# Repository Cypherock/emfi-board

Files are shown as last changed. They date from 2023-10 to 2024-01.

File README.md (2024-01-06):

# Cypherock EMFI Board

The Cypherock EMFI device is a low-cost Electromagnetic Fault Injection (EMFI) device, developed by Cypherock for studying and researching physical security threats that appear at a circuit level in modern chips.  

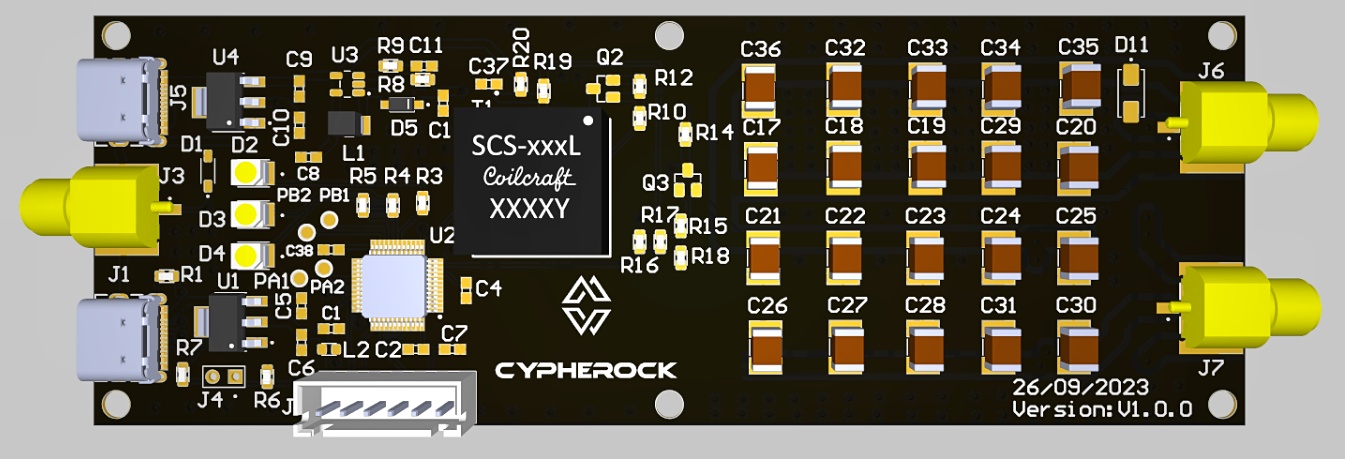
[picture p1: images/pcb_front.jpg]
pcb_front
      

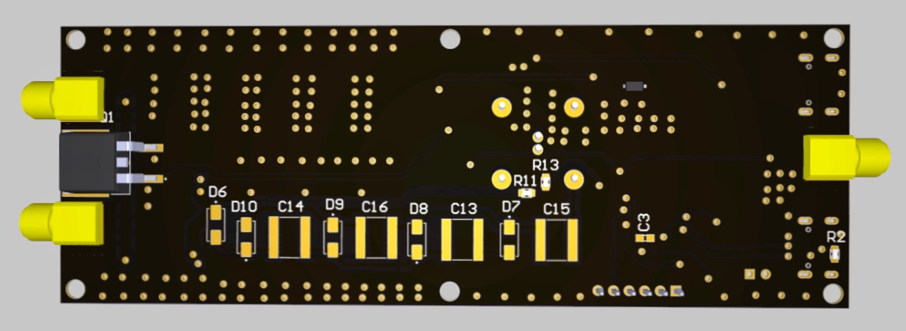
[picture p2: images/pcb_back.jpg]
pcb_back


## Background

Electromagnetic fault injection (EMFI) is used to disrupt the behavior of a chip and for weakening its security, typically targetting simple microcontrollers. It involves injecting electromagnetic shock at specific points on a target device's hardware to induce faults or errors. EMFI is one of the most common and popular physical attacks deployed or performed on various embedded systems, known for its capability to easily bypass and break through most of the security measures employed in modern chips. The following are two different attacks that can be performed using EMFI.

*Control Flow Manipulation Attacks* : 
Control flow manipulation in applications involves altering the execution order of instructions, often for malicious purposes. In embedded devices and microcontrollers, attackers can manipulate control flow without requiring vulnerabilities in the application code. Hardware attacks like voltage glitching, electromagnetic fault injection (EMFI), and laser fault injection (LFI) are employed to disrupt control flow and modify application code. These fault attacks can lead to unexpected behavior, including instruction skips, data corruption in memory, instruction modification, and tampering with the program counter. Such behavior can then be exploited by attackers to gain privileges, bypass security measures, extract information, inject malware, and more.

*Read Out Protection Bypass Attacks* : 
Read out protection (RDP) is a mechanism that restricts external access to the internals (flash memory and SRAM) of a microcontroller. Typically, this access is facilitated through a debug interface. However, depending on the application a microcontroller is used for, partial access might be sufficient for plotting attacks, for example only to the internal SRAM or some CPU registers. To compromise the RDP mechanism, physical attacks aims to interfere with the behavior of the underlying hardware implementations of a read-out protection. Again methods like voltage glitching and EMFI are perfect  for inducing faults in the MCUs code and operation. EMFI is a non-invasive attack method that does not require physical modifications to the microcontroller's hardware such as chip decapsulation etc. In practice, the read-out protection of some microcontrollers can be temporarily disabled and bypassed by applying a voltage glitch or injecting a pulse via EMFI during the power-up phase of the microcontrollers. 

## Working

The device is powered by USB. A programmable PWM signal is given as input from an STM32L4 MCU, this is used to control the output voltage (by changing the PWM parameters) generated by the device. When this signal is high the step up transformer will raise the voltage at its primary, converting the low voltage to high voltage at the secondary terminal. The step up transformer has primary to secondary winding ratio of 1:200. This voltage in the secondary is then again multiplied by a factor of “4” by the voltage multiplier and a very high voltage is generated. The charge is stored in the capacitor bank. All the capacitors used in this setup have a breakdown voltage of 1kV. The switching circuit is used to transfer this charge on to the EM probe. An external trigger or a controllable pulse is given as an input signal to the IGBT for a short period of time for switching. The external trigger can be given directly to the switching circuit to inject the fault, or through the MCU in which the MCU can modify or add delays to the signal programmatically. The MCU on its own can also be used to generate the pulse. When the IGBT is in ON state, the high voltage is transferred to the load which is the EM probe. Due to the high current that circulates in the coil of the probe, a magnetic field would be generated and the probe uses this electromagnetic field to transfer an electromagnetic shock to the DUT, injecting faults.

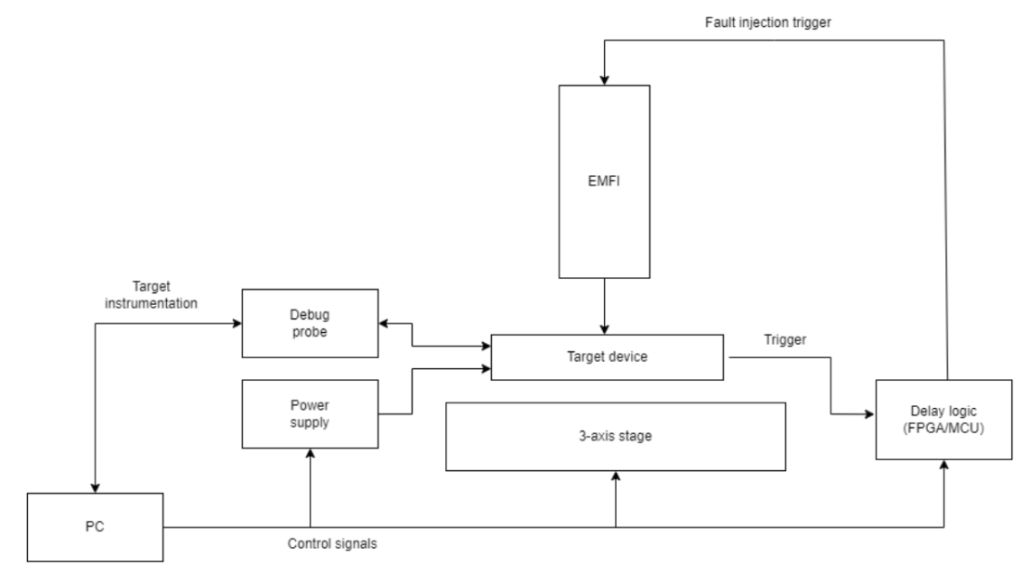
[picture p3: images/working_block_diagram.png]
working_block_diagram


The target microcontroller could be mounted on a 3-axis position stage. With this, the injection coil can be positioned precisely on the device and an automated grid scan can be performed. To ensure that the target device is always in a defined state, a programmable power supply source to power cycle the microcontroller should be used. Power-cycling could be applied before each measurement or for recovery, if the faulted microcontroller malfunctions. With the delay generator capability within the EMFI board, it is ensured that the fault is injected at the right point in time. A host PC could be used to control the entire setup and instrument the target microcontroller via a debug probe.

## Features

* Supports external power supply.  
* Supports external trigger or signal as input to generate pulse. 
* Supports modifying the signal programmatically.
* Programmable High Voltage Generation.
* Protection case to eliminate exposure to high voltage circuitry and for safe operation.
* Three on board LEDs for which can be used as indicators such as warning light etc.
* Low Input Power Requirement.
* Controlled Shock Injection.
* Two SMA Connectors to facilitate changing the polarity of the injected EM pulse.

## Electromagnetic (EM) Probe

The EM probe is required to inject shock into the target DUT. It can be constructed easily using a [power inductor](https://www.mouser.in/ProductDetail/710-744710610) and an [SMA connector](https://www.mouser.in/ProductDetail/712-CONSMA013.062-G). The power inductor would have a ferrite core wrapped around with coil. It converts the electrical energy into magnetic energy. The power inductor can be connected to an SMA connector to complete this setup. 

## Device Under Test (DUTs)   

The below list shows the microcontrollers that are commonly used in hardware crypto wallets. These microcontrollers are susceptible to EMFI based attacks. We have designed the DUT boards for EMFI analysis on these microcontrollers. These boards are included inside the hardware folder.

* STM32F205RET6
* STM32F427VIT6TR
* STM32L496RGT6
* STM32H753VIT6
* ESP32-D0WD-V3
* ATSAMD51J20A-AU
* ATMEGA328P-AU

## Usage

### EMFI firmware 
- STM32CubeIDE is required for building and debugging the project.
- After installation of the IDE, the project can be accessed by either using the .project/.cproject files.
- Use the launch configurations for debugging and programming the EMFI board.

### Use the EMFI tool for generating shoots
- Install python dependencies from requirements.txt
- Connect EMFI board's power and USB comm ports
- Run the python in Scripts/Cypherock/test.py
- Enter the COM port detected on the system
- After connection is created, EMFI voltage would start rising
- On pressing enter on the terminal, the device would start a EMFI shoot
- On pressing enter again, the device would turn off the PWM and voltage would gradually decrease

## License

Cypherock EMFI Board is released under [GNU General Public License](https://www.gnu.org/licenses/gpl-3.0.en.html) Version 3.

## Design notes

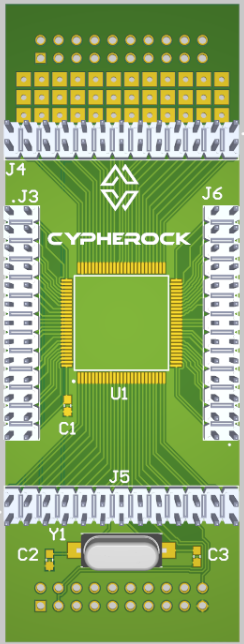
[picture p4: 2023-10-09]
images/DUT_STM32H753VIT6.png

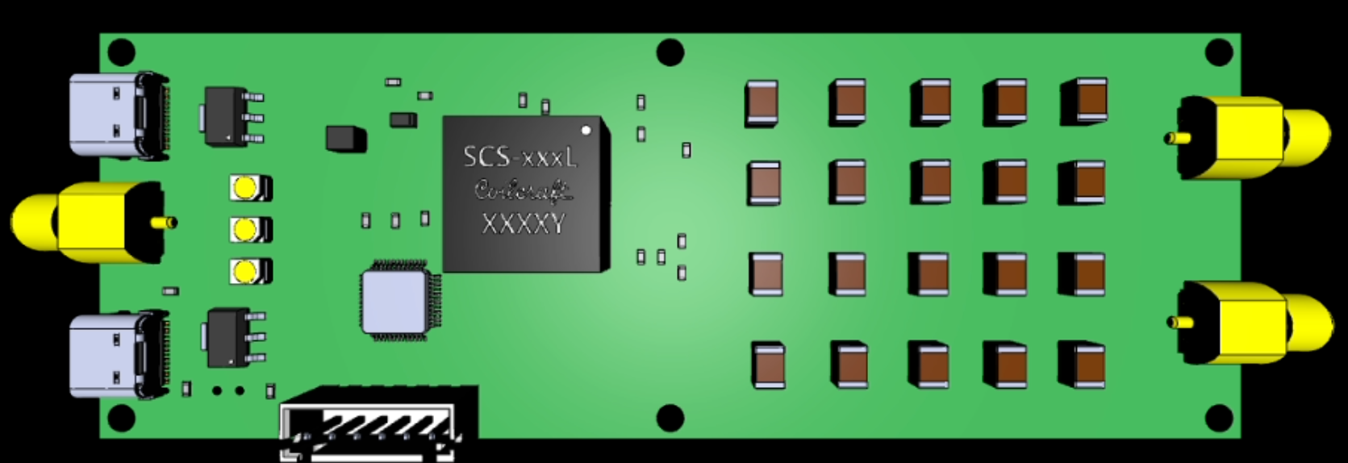
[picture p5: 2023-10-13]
images/pcb_3d_front.png

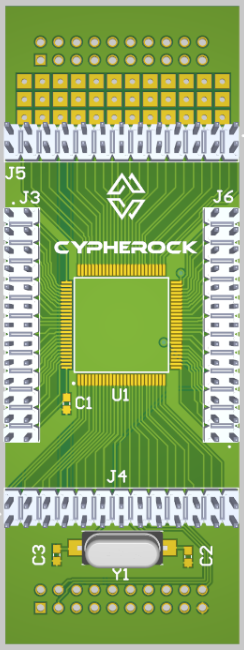
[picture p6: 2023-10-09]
images/DUT_STM32F427VIT6TR.png

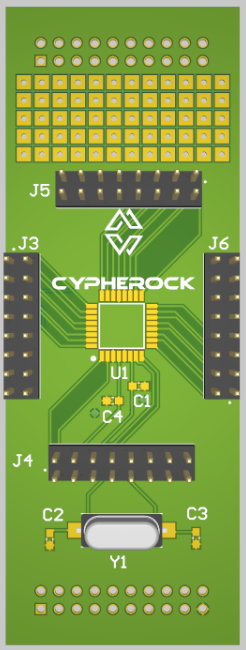
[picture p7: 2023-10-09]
images/DUT_ATMEGA328P-AU.png

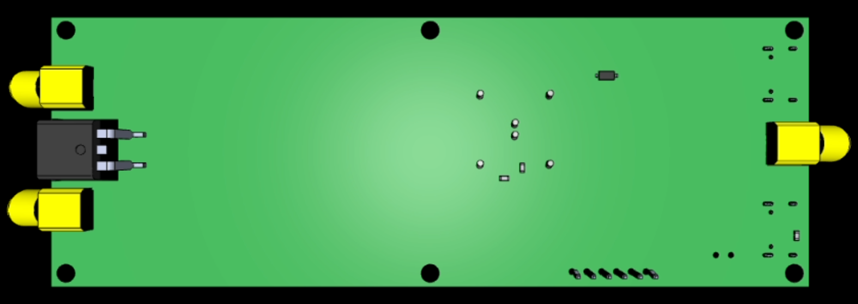
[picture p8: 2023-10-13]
images/pcb_3d_back.png

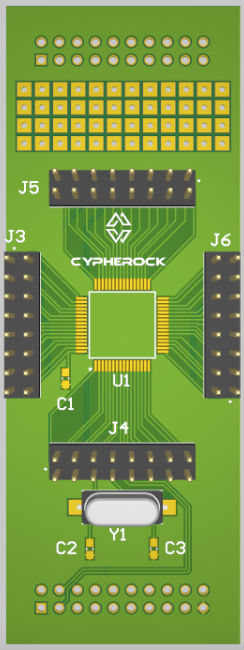
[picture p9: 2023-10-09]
images/DUT_STM32L496RGT6.png

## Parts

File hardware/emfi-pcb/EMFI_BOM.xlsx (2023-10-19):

Designator | Part Number | Description / Value | Package Description | Qty.
C1, C12 | GRM188Z71C475KE21D | 4.7uF/16V | 603 | 2
C2, C3, C4, C38 | CL10B105KO8NFNC | 1uF/16V | 603 | 4
C5, C6, C7, C8, C9, C10, C37 | GRT188R61C106KE13J | 10uF/16V | 0603, CAP CER 10UF 16V X5R 0603 | 7
C11 | VJ0603A4R7BXJPW1BC | 4.7pF/16V | 603 | 1
C13, C14, C15, C16 | C2225X154KDRACTU | 0.15uF/1000V | 2225 | 4
C17, C18, C19, C20, C21, C22, C23, C24, C25, C26, C27, C28, C29, C30, C31, C32, C33, C34, C35, C36 | C1812C104KDRAC7210 | 0.1uF/1000V | 1812 | 20
D1 | BZT52C3V3 | Zener Diode - Zener, SOD-123F, 3.3V, 0.5W, 5% | SOD-123F | 1
D2, D3, D4 | AA3528LSECKT/J4 | Standard LEDs - SMD 3.5mmX2.8mm SMD LED LAMP ORANGE | PLCC2 | 3
D5 | MBR0530T1G | Schottky Diodes & Rectifiers 0.5A 30V | SOD-123 | 1
D6, D7, D8, D9, D10, D11 | FR1M | Rectifiers Diode, Fast, SMA, 1000V, 1A, 150C | Diode Standard 1000 V 1A Surface Mount DO-214AC (SMA) | 6
J1, J5 | USB4105-GF-A-060 | USB Type-C | USB-C (USB TYPE-C) USB 2.0 Receptacle Connector 24 (16+8 Dummy) Position Surface Mount, Right Angle; Through Hole | 2
J2 | MP001799 | Pin Header - 2.5mm, 1 row 6 contact | Connector Header Through Hole 6 position 0.098 (2.50mm) | 1
J3, J6, J7 | SMA-J-P-H-ST-EM3 | SMA - RF Connectors / Coaxial Connectors 6 GHz, 50 Ohm SMA Jack or Plug, Cable Connector | RF Connectors / Coaxial Connectors | 3
J4 | 87224-2 | Connector Unshrouded Header HDR 2 Position 2.54mm Solder Straight Thru-Hole | Connector Unshrouded Header HDR 2 Position 2.54mm Solder Straight Thru-Hole | 1
L1 | NLCV32T-6R8M-EF | RF Inductor - 6.8uH | 1210 | 1
L2 | MPZ1608S102ATD25 | Ferrite Beads 0603 1000ohms 800mA Power Line AEC-Q200 | 603 | 1
PA1, PA2, PB1, PB2 | 5019 |  | SMT Test Point- Mininature-1000 pc Reels | 4
Q1 | IXGA30N120B3 | IGBT Transistor - GenX3 1200V IGBT | TO-263-3 | 1
Q2, Q3 | IRLML6344TRPBF | MOSFET - N channel - 40Vds 20Vgs 20A 5.0A 93pF 1.2W | SOT-23-3 | 2
R1, R2 | CRCW06034K75FKEA | 4.75k/0.1W | RES 0.27 OHM 1% 1/10W 0603 | 2
R3, R4, R5 | RT0603FRE072KL | 2k/0.1W | RES 0.27 OHM 1% 1/10W 0603 | 3
R6, R12, R13, R14, R15, R18 | RC0603FR-0710KL | 10k/0.1W | RES 0.27 OHM 1% 1/10W 0603 | 6
R7, R19 | AC0603FR-070RL | 0E/0.1W | RES 0.27 OHM 1% 1/10W 0603 | 2
R8 | CRCW06031M80FKEAC | 1.8M/0.1W | RES 0.27 OHM 1% 1/10W 0603 | 1
R9 | RC0603FR-07205KL | 205k/0.1W | RES 0.27 OHM 1% 1/10W 0603 | 1
R10, R17 | CRCW0603100RFKEAC | 100E/0.1W | RES 0.27 OHM 1% 1/10W 0603 | 2
R11 | CRCW060310M0FKEAC | 10M/0.1W | RES 0.27 OHM 1% 1/10W 0603 | 1
R16, R20 | AC0603FR-070RL | 0E/0.1W DNP | RES 0.27 OHM 1% 1/10W 0603 | 2
T1 | SCS-200LD | Transformer |  | 1
U1, U4 | TLV1117LV33 | Voltage Regulator - LDO Voltage Regulators LDO BJT | 1-A, low-dropout voltage regulator | 2
U2 | STM32L412C8T6 | MCU | STMICROELECTRONICS - STM32L412C8T6 - MCU, 32BIT, 80MHZ | 1
U3 | TPS61040QDBVRQ1 | Switching Voltage Regulators Auto Cat Low Pwr DC/DC Boost Cnvrtr |  | 1

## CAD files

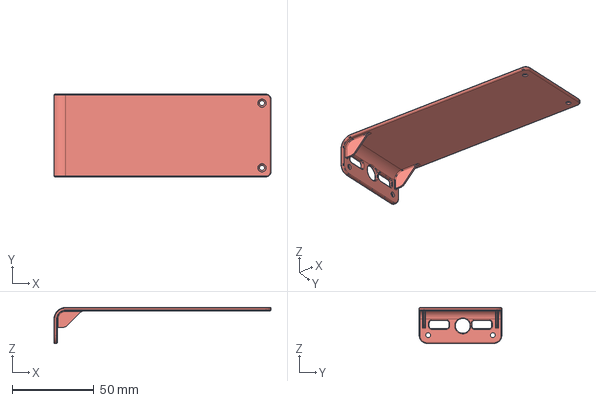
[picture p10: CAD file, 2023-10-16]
hardware/emfi-enclosure/enclosure_top.step
132.6 x 50.5 x 22.0 mm

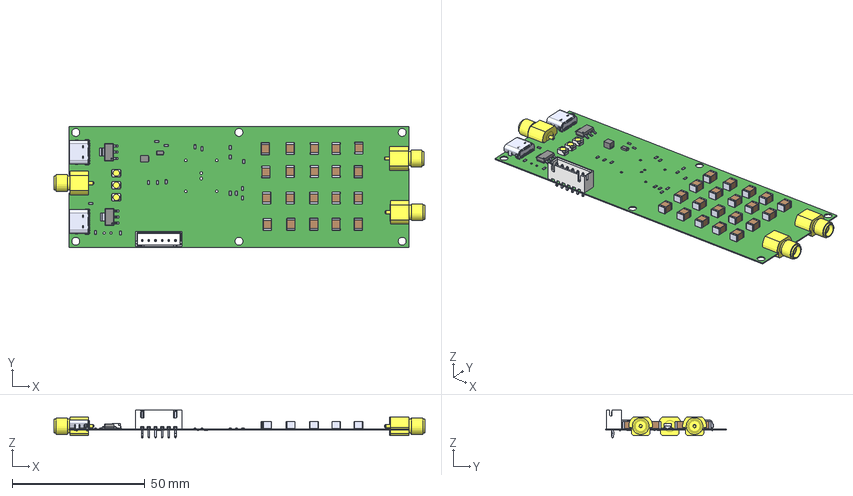
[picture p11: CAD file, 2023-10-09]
hardware/emfi-pcb/EMFI_3D.step
139.8 x 45.6 x 10.4 mm
USB4105 x 2
SMA-J-P-H-ST-EM3 x 3

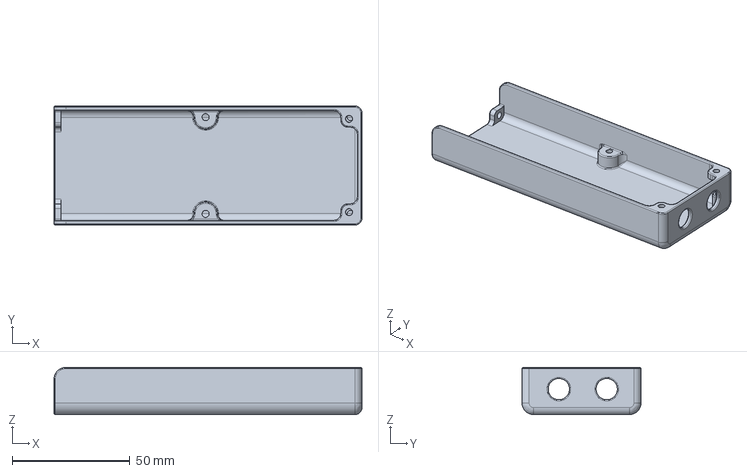
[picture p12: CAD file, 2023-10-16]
hardware/emfi-enclosure/enclosure_bottom.step
130.6 x 50.5 x 20.0 mm

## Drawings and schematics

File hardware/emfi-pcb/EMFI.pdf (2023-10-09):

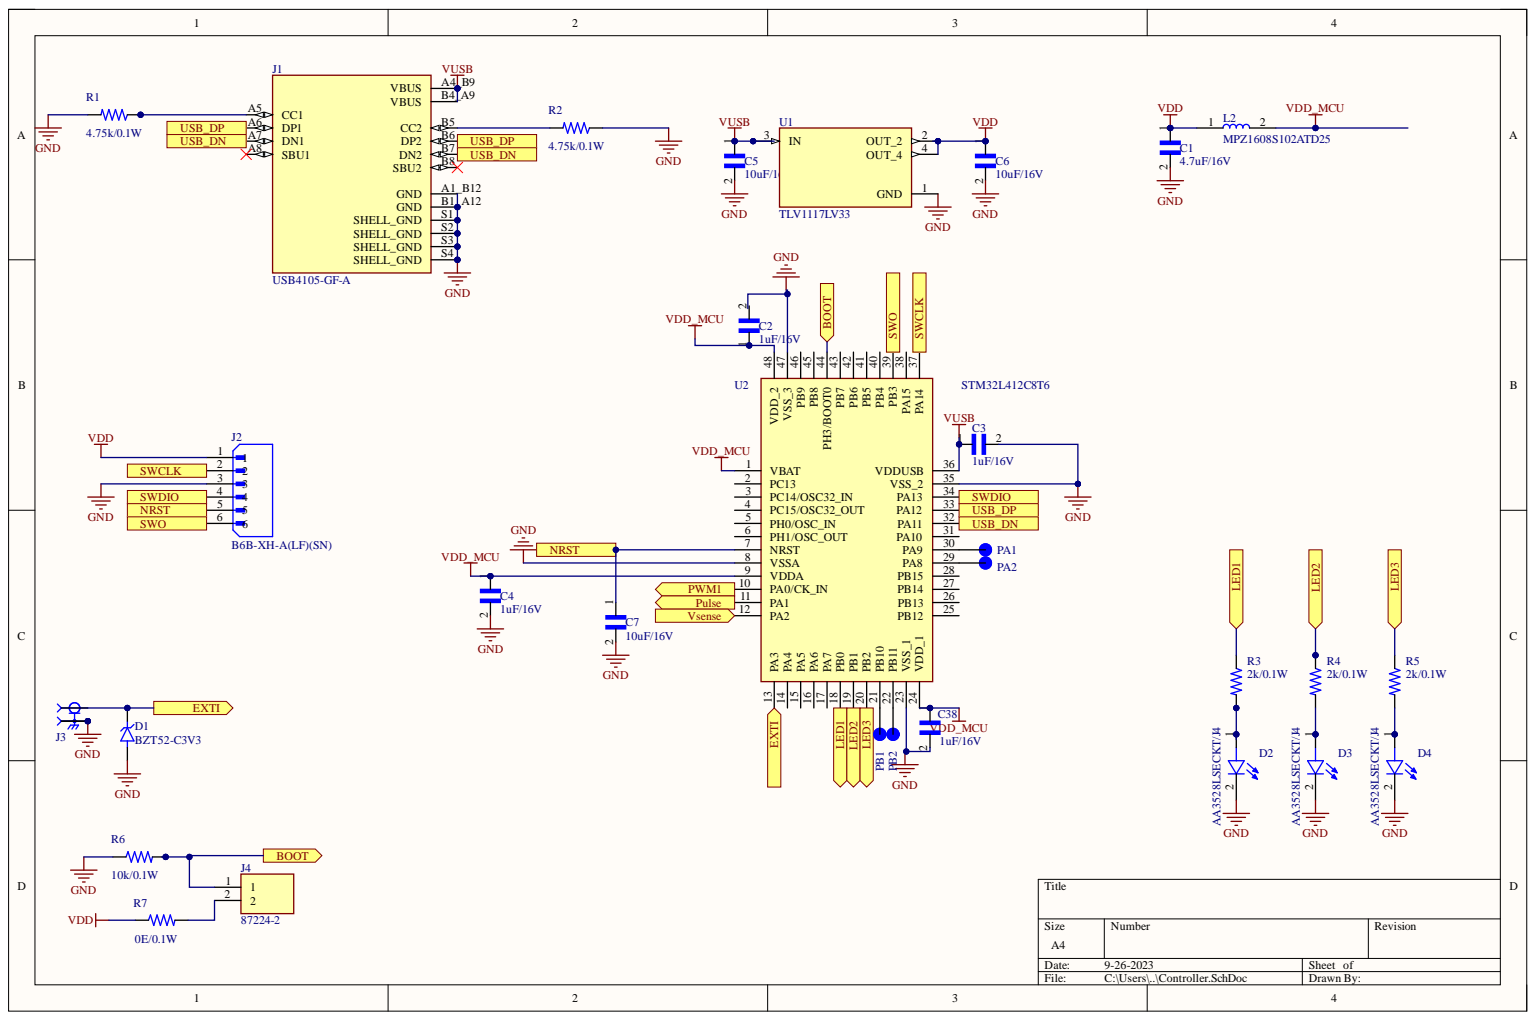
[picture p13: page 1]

VSSA 8

PWM1 | PA0/CK_IN 10

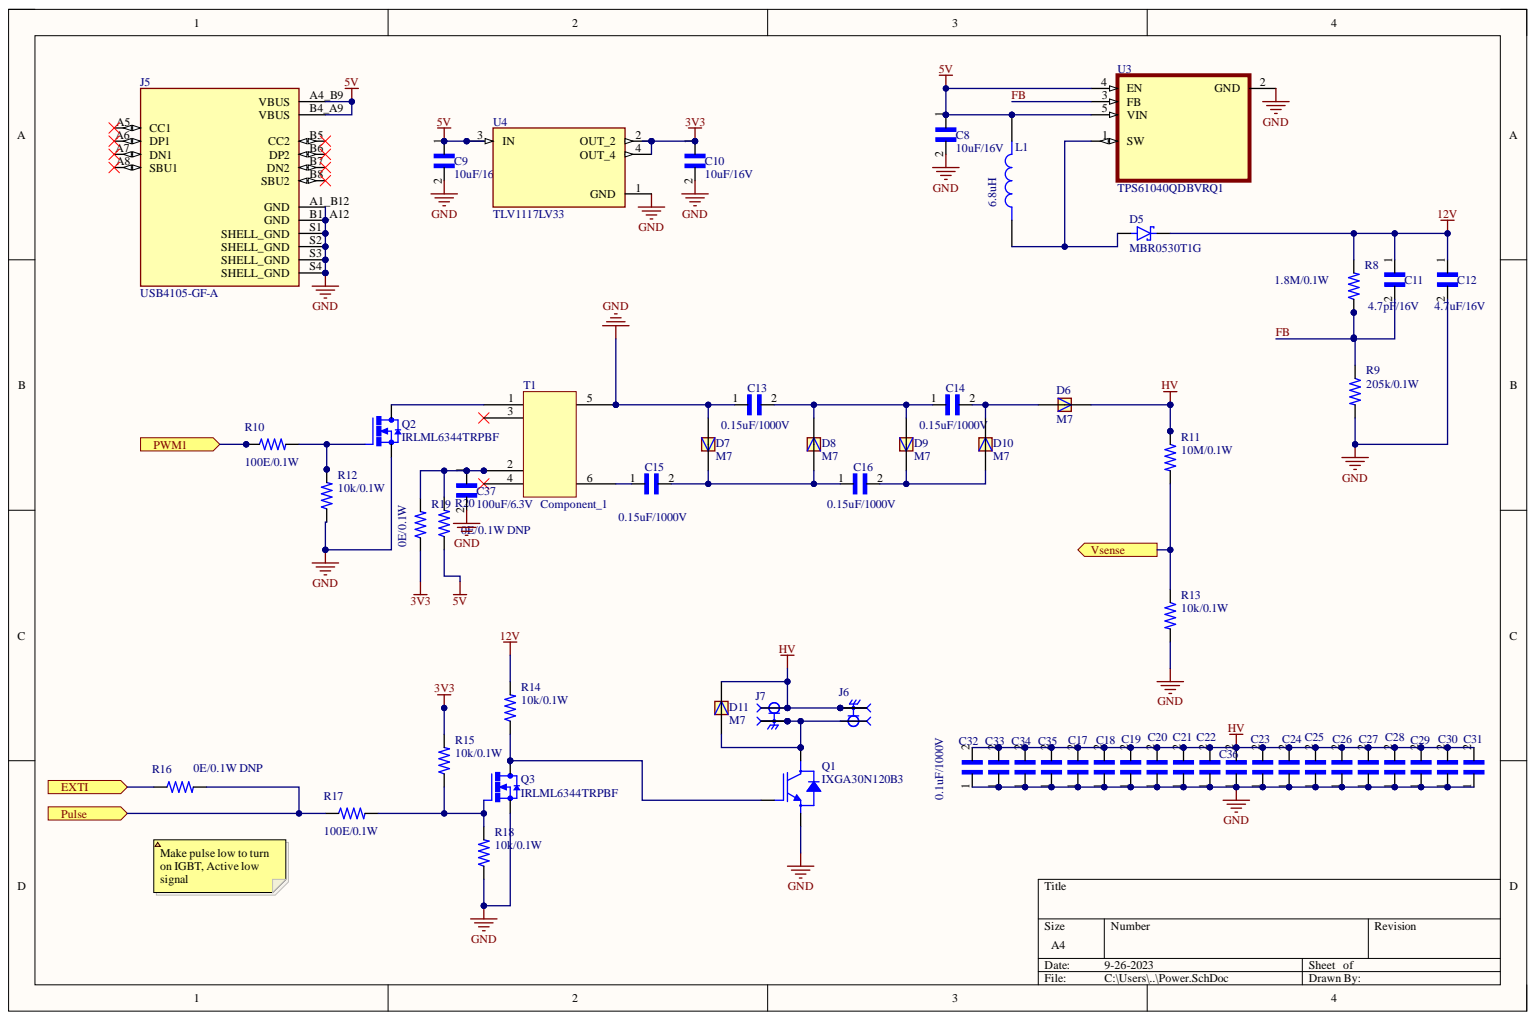
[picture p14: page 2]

Make pulse low to turn
on IGBT, Active low
signal

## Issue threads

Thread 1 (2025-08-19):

Fatal error in Q1 driver !!!

trojkowy, 2025-08-19:
This design has some bugs. After fully assembling the device and connecting it to the supply voltage, Q1 self-excites and blows up. 1. This transistor should be controlled by a gate driver not by Q3! . 2. You have two logical states set in Q3 via R15 to VCC and via R18 to GND. Even if you remove one logical state by desoldering the resistor, each subsequent Q1 still lights up and blows up. During my third attempt to replace the burned-out Q1 with a new one from the MOUSER store, this time I fried many other components, including the STM32 processor. Thank you f

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

or this wonderful project!

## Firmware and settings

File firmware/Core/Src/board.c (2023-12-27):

/*
 * board.c
 *
 *  Created on: Nov 5, 2023
 *      Author: akuan
 */
#include "board.h"

#include "pid.h"
ADC_HandleTypeDef hadc1;
DMA_HandleTypeDef hdma_adc1;

TIM_HandleTypeDef htim2;
TIM_HandleTypeDef htim6;

PID_TypeDef TPID;
system_info_t sysInfo;
uint8_t performShoot = 1;

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
/* USER CODE BEGIN 4 */
uint16_t BSP_DMA_Count(void)
{
	uint16_t count =  __HAL_DMA_GET_COUNTER(&hdma_adc1);
	return count;
}

void BSP_TIM_PWM_CH1_Start(void)
{
	HAL_TIM_PWM_Start(&htim2, TIM_CHANNEL_1);
}

void BSP_TIM_PWM_CH2_Start(void)
{
	HAL_TIM_PWM_Start(&htim2, TIM_CHANNEL_2);
}

void BSP_Start_ADC_IT(void)
{

	HAL_ADC_Start_IT(&hadc1);
}

HAL_StatusTypeDef BSP_ReadVoltage(uint16_t *pData, uint16_t Size)
{
	HAL_StatusTypeDef status = HAL_OK;
	status = HAL_ADC_Start_DMA(&hadc1, (uint32_t*)pData, Size);
	if (status != HAL_OK)
		return HAL_ERROR;
	return HAL_OK;
}

void HAL_TickCallBack(void)
{


}
uint8_t isPWM_Generation_Start = 0;
uint8_t isPWM_Stoped = 0;
uint32_t adc_set_point_value = 400;


void update_dutyCycle()
{
	int diffValue =  adc_set_point_value - sysInfo.adcDataReadBuffer;

	uint32_t percentValue = ((float)diffValue / adc_set_point_value) *100;
	if (percentValue < 0)
	{
		HAL_TIM_PWM_Stop(&htim2, TIM_CHANNEL_1);
	}
	else if ((percentValue < 40) && percentValue)
	{
		TIM2->CCR1  = (39) *percentValue;
	}
	else if (percentValue == 0)
	{
		TIM2->CCR1 = (39);
	}
	else
	{
		TIM2->CCR1 = 1599;
	}

}
void HAL_ADC_ConvCpltCallback(ADC_HandleTypeDef* hadc)
{
	// Read & Update The ADC Result
	sysInfo.adcDataReadBuffer = HAL_ADC_GetValue(&hadc1);
	sysInfo.adcDataReadBuffer += (sysInfo.PIDOut / 100);
	//PID_Compute(&TPID);
	if (isPWM_Generation_Start)
	{
		if (sysInfo.adcDataReadBuffer > adc_set_point_value)
		{
			if (isPWM_Stoped == 0)
			{
				HAL_TIM_PWM_Stop(&htim2, TIM_CHANNEL_1);
				HAL_GPIO_WritePin(GPIOB,LED3_PIN_Pin, GPIO_PIN_SET);
				isPWM_Stoped = 1;
			}
		}
		else
		{
			if (isPWM_Stoped)
			{
				//sysInfo.CH1_ARR = ((3*pwmValue->pwmWidth) - 1);
				//sysInfo.CH1_DC = (((sysInfo.CH1_ARR + 1) /100) *(pwmValue->pwmPeriod));
				TIM2->CCR1 = 399;
				TIM2->ARR = 3999;
				HAL_TIM_PWM_Start(&htim2, TIM_CHANNEL_1);
				isPWM_Stoped = 0;
			}

			HAL_GPIO_WritePin(GPIOB,LED3_PIN_Pin, GPIO_PIN_RESET);

			//update_dutyCycle();


		}
	}
}


void BSP_Config_PID(void)
{

	PID(&TPID, &sysInfo.Volt, &sysInfo.PIDOut, &sysInfo.VoltSetpoint, 2, 5, 1, _PID_P_ON_E, _PID_CD_DIRECT);

	PID_SetMode(&TPID, _PID_MODE_AUTOMATIC);
	PID_SetSampleTime(&TPID, 500);
	PID_SetOutputLimits(&TPID, -100, 100);
}

#include "usbd_cdc_if.h"
uint8_t SendBuffer[128] = { 0 };
uint8_t commandResponce = 0;
typedef struct
{
	uint16_t pwmWidth;
	uint16_t pwmPeriod;

}pwm_setting_t;
pwm_setting_t pwmSetting = { 800, 1};
uint8_t dataRead[128] = { 0 };
void parse_cmd(uint8_t cmd, uint8_t * data, uint8_t size)
{
	switch(cmd)
	{
		case ACTIVATE_VOLT_GENERATER:
		{
			commandResponce = cmd;
			CDC_Transmit_FS((uint8_t *)&commandResponce, sizeof(uint8_t));
			uint8_t * value = (uint8_t *)data;
			isPWM_Generation_Start = *value;
			isPWM_Stoped = 1;
			//isPWM_Generation_Start = 1;
			break;
		}

		case GET_RAW_VALUE:
		{
			uint16_t readAdc = sysInfo.adcDataReadBuffer;
			CDC_Transmit_FS((uint8_t *)&readAdc, sizeof(uint16_t));
			break;
		}

		case SET_PWM_VALUE:
		{

			CDC_Transmit_FS((uint8_t *)&cmd, 1);
			pwm_setting_t * pwmValue = (pwm_setting_t *)data;

			sysInfo.CH1_ARR = ((3*pwmValue->pwmWidth) - 1);
			sysInfo.CH1_DC = (((sysInfo.CH1_ARR + 1) /100) *(pwmValue->pwmPeriod));
			//BSP_TIM_PWM_CH1_Start();
			break;
		}


		case PERFORM_SOFTWARE_SHOOT:
			CDC_Transmit_FS((uint8_t *)&cmd, 1);
			TIM6_Start();
			nopCount++;
			performShoot = 1;
			break;
		case GET_SYSTEM_TIME:
		{
			uint64_t currentTime = HAL_GetTick();
			memcpy(SendBuffer,(uint8_t *)&currentTime,sizeof(uint64_t));
			CDC_Transmit_FS((uint8_t *)&SendBuffer, sizeof(uint64_t));
		}
			break;
		case GET_ADC_CONTROL_SETPOINT:
			CDC_Transmit_FS((uint8_t *)&sysInfo.pidLimit.setpoint, sizeof(uint32_t));
			break;
		case SET_ADC_CONTROL_SETPOINT:
			break;
		case GET_PWM_VALUE:

			CDC_Transmit_FS((uint8_t *)&pwmSetting.pwmWidth, sizeof(uint32_t));
			pwmSetting.pwmPeriod = 5;
			CDC_Transmit_FS((uint8_t *)&pwmSetting.pwmPeriod, sizeof(uint32_t));
			break;
		case READ_PID_VALUE:
			memcpy(SendBuffer,(uint8_t *)&sysInfo.pidConfig,sizeof(pid_config_t));
			CDC_Transmit_FS((uint8_t *)&SendBuffer, sizeof(pid_config_t));
			break;
		case SET_PID_VALUE:
			break;
		case SET_PID_LIMIT_VALUE:
			break;
		case READ_PID_LIMIT_VALUE:
			memcpy(SendBuffer,(uint8_t *)&sysInfo.pidLimit,sizeof(pid_limit_t));
			CDC_Transmit_FS((uint8_t *)&SendBuffer, sizeof(pid_limit_t));
			break;
		case SET_ADC_SET_POINT:
		{
			uint16_t * value = (uint16_t *)data;
			adc_set_point_value = *value;
			break;
		}
	}
}
/* USER CODE END 4 */

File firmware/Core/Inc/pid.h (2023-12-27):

 /*
------------------------------------------------------------------------------
~ File   : pid.h
~ Author : Majid Derhambakhsh
~ Version: V1.0.0
~ Created: 02/11/2021 03:43:00 AM
~ Brief  :
~ Support:
		   E-Mail : Majid.do16@gmail.com (subject : Embedded Library Support)

		   Github : https://github.com/Majid-Derhambakhsh
------------------------------------------------------------------------------
~ Description:

~ Attention  :

~ Changes    :
------------------------------------------------------------------------------
*/

#ifndef __PID_H_
#define __PID_H_

/* ~~~~~~~~~~~~~~~~~~~~~~~~~~~~~~~~~~~~~~~~~~~~~~~~~~~~~~~~~~ Include ~~~~~~~~~~~~~~~~~~~~~~~~~~~~~~~~~~~~~~~~~~~~~~~~~~~~~~~~~~ */
#include <stdint.h>
#include <string.h>

/* ------------------------------------------------------------------ */

#ifdef __CODEVISIONAVR__  /* Check compiler */

#pragma warn_unref_func- /* Disable 'unused function' warning */

/* ------------------------------------------------------------------ */

#elif defined(__GNUC__) && !defined(USE_HAL_DRIVER)  /* Check compiler */

#pragma GCC diagnostic ignored "-Wunused-function" /* Disable 'unused function' warning */

/* ------------------------------------------------------------------ */

#elif defined(USE_HAL_DRIVER)  /* Check driver */

	#include "main.h"

	/* --------------- Check Mainstream series --------------- */

	#ifdef STM32F0
		#include "stm32f0xx_hal.h"       /* Import HAL library */
	#elif defined(STM32F1)
		#include "stm32f1xx_hal.h"       /* Import HAL library */
	#elif defined(STM32F2)
		#include "stm32f2xx_hal.h"       /* Import HAL library */
	#elif defined(STM32F3)
		#include "stm32f3xx_hal.h"       /* Import HAL library */
	#elif defined(STM32F4)
		#include "stm32f4xx_hal.h"       /* Import HAL library */
	#elif defined(STM32F7)
		#include "stm32f7xx_hal.h"       /* Import HAL library */
	#elif defined(STM32G0)
		#include "stm32g0xx_hal.h"       /* Import HAL library */
	#elif defined(STM32G4)
		#include "stm32g4xx_hal.h"       /* Import HAL library */

	/* ------------ Check High Performance series ------------ */

	#elif defined(STM32H7)
		#include "stm32h7xx_hal.h"       /* Import HAL library */

	/* ------------ Check Ultra low power series ------------- */

	#elif defined(STM32L0)
		#include "stm32l0xx_hal.h"       /* Import HAL library */
	#elif defined(STM32L1)
		#include "stm32l1xx_hal.h"       /* Import HAL library */
	#elif defined(STM32L5)
		#include "stm32l5xx_hal.h"       /* Import HAL library */
	#elif defined(STM32L4)
		#include "stm32l4xx_hal.h"       /* Import HAL library */
	#elif defined(STM32H7)
		#include "stm32h7xx_hal.h"       /* Import HAL library */
	#else
	#endif /* STM32F1 */

	/* ------------------------------------------------------- */

	#if defined ( __ICCARM__ ) /* ICCARM Compiler */

	#pragma diag_suppress=Pe177   /* Disable 'unused function' warning */

	#elif defined   (  __GNUC__  ) /* GNU Compiler */

	#pragma diag_suppress 177     /* Disable 'unused function' warning */

	#endif /* __ICCARM__ */

/* ------------------------------------------------------------------ */

#else                     /* Compiler not found */

#error Chip or Library not supported  /* Send error */

#endif /* __CODEVISIONAVR__ */

/* ------------------------------------------------------------------ */

/* ~~~~~~~~~~~~~~~~~~~~~~~~~~~~~~~~~~~~~~~~~~~~~~~~~~~~~~~~~~ Defines ~~~~~~~~~~~~~~~~~~~~~~~~~~~~~~~~~~~~~~~~~~~~~~~~~~~~~~~~~~ */
/* ------------------------ Library ------------------------ */
#define _PID_LIBRARY_VERSION    1.0.0

/* ------------------------ Public ------------------------- */
#define _PID_8BIT_PWM_MAX       UINT8_MAX
#define _PID_SAMPLE_TIME_MS_DEF 100

#ifndef _FALSE

	#define _FALSE 0

#endif

#ifndef _TRUE

	#define _TRUE 1

#endif

/* ---------------------- By compiler ---------------------- */
#ifndef GetTime

	/* ---------------------- By compiler ---------------------- */

	#ifdef __CODEVISIONAVR__  /* Check compiler */

		#define GetTime()   0

	/* ------------------------------------------------------------------ */

	#elif defined(__GNUC__) && !defined(USE_HAL_DRIVER)  /* Check compiler */

		#define GetTime()   0

	/* ------------------------------------------------------------------ */

	#elif defined(USE_HAL_DRIVER)  /* Check driver */

		#define GetTime()   HAL_GetTick()

	/* ------------------------------------------------------------------ */

	#else
	#endif /* __CODEVISIONAVR__ */
	/* ------------------------------------------------------------------ */

#endif

/* --------------------------------------------------------- */

/* ~~~~~~~~~~~~~~~~~~~~~~~~~~~~~~~~~~~~~~~~~~~~~~~~~~~~~~~~~~~ Types ~~~~~~~~~~~~~~~~~~~~~~~~~~~~~~~~~~~~~~~~~~~~~~~~~~~~~~~~~~~ */
/* PID Mode */
typedef enum
{
	
	_PID_MODE_MANUAL    = 0,
	_PID_MODE_AUTOMATIC = 1
	
}PIDMode_TypeDef;

/* PID P On x */
typedef enum
{
	
	_PID_P_ON_M = 0, /* Proportional on Measurement */
	_PID_P_ON_E = 1
	
}PIDPON_TypeDef;

/* PID Control direction */
typedef enum
{
	
	_PID_CD_DIRECT  = 0,
	_PID_CD_REVERSE = 1
	
}PIDCD_TypeDef;

/* PID Structure */
typedef struct
{
	
	PIDPON_TypeDef  POnE;
	PIDMode_TypeDef InAuto;

	PIDPON_TypeDef  POn;
	PIDCD_TypeDef   ControllerDirection;

	uint32_t        LastTime;
	uint32_t        SampleTime;

	double          DispKp;
	double          DispKi;
	double          DispKd;

	double          Kp;
	double          Ki;
	double          Kd;

	double          *MyInput;
	double          *MyOutput;
	double          *MySetpoint;

	double          OutputSum;
	double          LastInput;

	double          OutMin;
	double          OutMax;
	
}PID_TypeDef;

/* ~~~~~~~~~~~~~~~~~~~~~~~~~~~~~~~~~~~~~~~~~~~~~~~~~~~~~~~~~ Variables ~~~~~~~~~~~~~~~~~~~~~~~~~~~~~~~~~~~~~~~~~~~~~~~~~~~~~~~~~ */
/* ~~~~~~~~~~~~~~~~~~~~~~~~~~~~~~~~~~~~~~~~~~~~~~~~~~~~~~~~~~~ Enum ~~~~~~~~~~~~~~~~~~~~~~~~~~~~~~~~~~~~~~~~~~~~~~~~~~~~~~~~~~~~ */
/* ~~~~~~~~~~~~~~~~~~~~~~~~~~~~~~~~~~~~~~~~~~~~~~~~~~~~~~~~~~ Struct ~~~~~~~~~~~~~~~~~~~~~~~~~~~~~~~~~~~~~~~~~~~~~~~~~~~~~~~~~~~ */
/* ~~~~~~~~~~~~~~~~~~~~~~~~~~~~~~~~~~~~~~~~~~~~~~~~~~~~~~~~~~~ Class ~~~~~~~~~~~~~~~~~~~~~~~~~~~~~~~~~~~~~~~~~~~~~~~~~~~~~~~~~~~ */
/* ~~~~~~~~~~~~~~~~~~~~~~~~~~~~~~~~~~~~~~~~~~~~~~~~~~~~~~~~~ Prototype ~~~~~~~~~~~~~~~~~~~~~~~~~~~~~~~~~~~~~~~~~~~~~~~~~~~~~~~~~ */
/* :::::::::::::: Init ::::::::::::: */
void PID_Init(PID_TypeDef *uPID);

void PID(PID_TypeDef *uPID, double *Input, double *Output, double *Setpoint, double Kp, double Ki, double Kd, PIDPON_TypeDef POn, PIDCD_TypeDef ControllerDirection);
void PID2(PID_TypeDef *uPID, double *Input, double *Output, double *Setpoint, double Kp, double Ki, double Kd, PIDCD_TypeDef ControllerDirection);

/* ::::::::::: Computing ::::::::::: */
uint8_t PID_Compute(PID_TypeDef *uPID);

/* ::::::::::: PID Mode :::::::::::: */
void            PID_SetMode(PID_TypeDef *uPID, PIDMode_TypeDef Mode);
PIDMode_TypeDef PID_GetMode(PID_TypeDef *uPID);
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

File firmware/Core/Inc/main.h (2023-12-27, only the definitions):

#define LED1_PIN_Pin GPIO_PIN_0
#define LED1_PIN_GPIO_Port GPIOB
#define LED2_PIN_Pin GPIO_PIN_1
#define LED2_PIN_GPIO_Port GPIOB
#define LED3_PIN_Pin GPIO_PIN_2
#define LED3_PIN_GPIO_Port GPIOB

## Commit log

2023-10-09 Initial design for EMFI and DUT boards uploaded
    [ATECC.PcbDoc, ATECC.PrjPcb, ATECC.SchDoc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]
2023-10-13 Added dut boards gerber files
    [ATECC_Copper_Signal_Bot.gbr, ATECC_Copper_Signal_Top.gbr, ATECC_Drawing_1.gbr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]
2023-10-13 Added updated files with 3d components
    [EMFI.PcbDoc, Power.SchDoc]
2023-12-27 Added firmware for emfi board testing

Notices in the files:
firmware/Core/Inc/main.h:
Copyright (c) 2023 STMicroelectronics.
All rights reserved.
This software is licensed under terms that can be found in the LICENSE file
